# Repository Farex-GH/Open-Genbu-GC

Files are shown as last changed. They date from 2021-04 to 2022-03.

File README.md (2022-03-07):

# Open-Genbu-GC
Replacement PCB and firmware for Genbu Groove Coaster controllers

For firmware building and flashing instructions, see firmware/README.md.

Pre-built firmware is available in the Releases tab.

For PCB and schematic viewing, download KiCad and open the respective PCB/*.kicad_pro file.

## WIP

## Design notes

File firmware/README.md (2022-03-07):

BUILD INSTRUCTIONS

1. git clone the repsoitory

2. cd genbu-fw/firmware

3. git submodule update --init

4. ./setup,sh

5. mkdir build

6. cd build

7. cmake ..

8. make -j4

FIRMWARE FLASH INSTRUCTIONS

1. Plug in Raspberry Pi Pico to a PC. If reflashing, hold down the BOOTSEL button while plugging it in.

2. Copy genbu-fw.uf2 from build directory to Raspberry Pi Pico directory

DEBUGGING

1. See https://datasheets.raspberrypi.com/pico/getting-started-with-pico.pdf Ch.5 and 6.

There are useful macros provided for printing via UART and GPIO toggling.
For more timing sensitve situations, use the GPIO toggling to see when certain parts of code are hit.
Otherwise if timing is not a problem, DB_PRINT works fine.

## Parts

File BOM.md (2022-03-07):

# WIP
## Will be converted to an excel sheet for easier reading

2x SMR-03v-B from https://lcsc.com/product-detail/Rectangular-Connectors-Housings_JST-Sales-America-SMR-03V-B_C157907.html, plus wires
Or buy premade female connectors from Amazon if you search "ws2812b connector"

11x B4B-XH-A(LF)(SN) from https://lcsc.com/product-detail/Wire-To-Board-Wire-To-Wire-Connector_JST-Sales-America_B4B-XH-A-LF-SN_JST-Sales-America-B4B-XH-A-LF-SN_C144395.html

1x Pi Pico module from https://www.adafruit.com/product/4883 or wherever you can get it

1x USB-A to micro USB-B cable, for front PCB to Pi Pico.

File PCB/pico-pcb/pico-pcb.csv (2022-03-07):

Id | Designator | Package | Quantity | Designation | Supplier and ref
1 | J12,J13,J16 | PinSocket_1x03_P2.54mm_Vertical | 3 | Conn_01x03
2 | J15 | PinSocket_1x02_P2.54mm_Vertical | 1 | Conn_01x02
3 | J14 | PinSocket_1x04_P2.54mm_Vertical | 1 | Conn_01x04
4 | J1,J2,J3,J4,J5,J6,J7,J8,J9,J10,J11 | JST_B4B-XH-A(LF)(SN) | 11 | B4B-XH-A_LF__SN_
5 | U1 | RPi_Pico_SMD_TH | 1 | Pico

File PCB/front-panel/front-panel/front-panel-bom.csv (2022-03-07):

Id | Designator | Package | Quantity | Designation | Supplier and ref
1 | J2 | USB_A_Molex_105057_Vertical | 1 | USB_A
2 | J1 | USB_B_TE_5787834_Vertical | 1 | USB_B

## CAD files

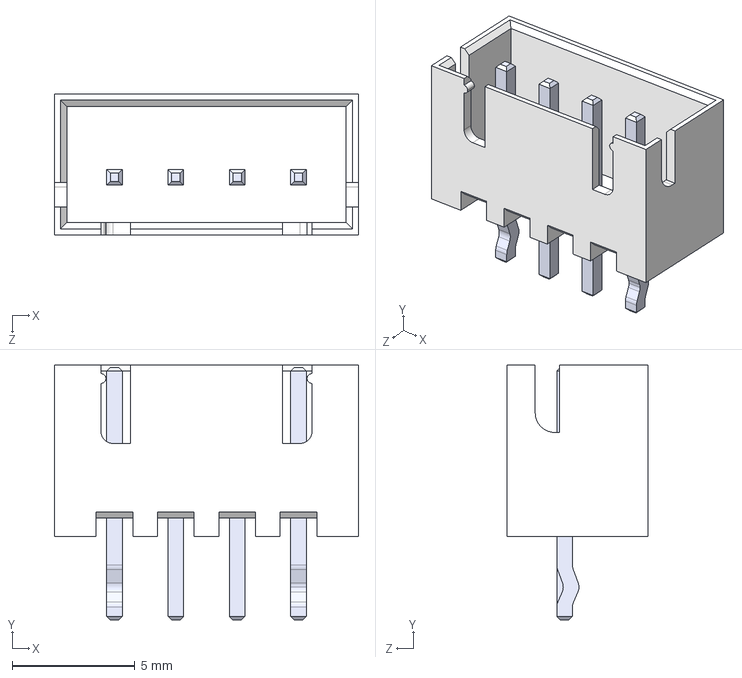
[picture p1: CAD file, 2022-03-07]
PCB/pico-pcb/RP_Silicon_KiCad/B4B-XH-A(LF)(SN)/B4B-XH-A_LF__SN_.step
12.4 x 10.4 x 5.75 mm

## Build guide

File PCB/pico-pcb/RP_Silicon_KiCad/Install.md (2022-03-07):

# Install KiCad libraries

## Manage Symbol Libraries

Accessed from the Preferences menu, add a new line with the +, give it a name and use the folder icon to point to the directory/folder where you have KiCadLibraries.

Manage Symbol Libraries screen shot


## Manage Footprint Libraries

Ditto! Accessed from the Preferences menu, add a new line with the +, give it a name and use the folder icon to point to the directory/folder where you have KiCadLibraries.

Manage Footprint Libraries screen shot


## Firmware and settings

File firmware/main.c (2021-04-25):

#include <stdlib.h>

#include "pico/stdlib.h"
#include "pico/multicore.h"

#include "proc_queue.h"
#include "usb_driver.h"
#include "usb_gamepad.h"
#include "utils.h"
#include "arm_utils.h"
#include "board_io.h"
#include "ws2812.h"

void control_loop(void)
{
    proc_info *proc;

    while (1) {
        proc = proc_next();
        if (proc) {
            proc->proc_fn(proc->pfn_args);
        } else {
            __DSB;
            __WFI;
        }
    }
}

void dbg_gpio_init(void)
{
    gpio_init(PIN_DBG_0);
    gpio_init(PIN_DBG_1);
    gpio_init(PIN_DBG_2);
    gpio_set_dir(PIN_DBG_0, true);
    gpio_set_dir(PIN_DBG_1, true);
    gpio_set_dir(PIN_DBG_2, true);
}

int main(void) {
    stdio_init_all();
    usb_ep_add_callback(0x81, ep1_in_cb);
    usb_ep_add_callback(0x02, ep2_out_cb);
    usb_device_init();
    proc_init();
    board_io_init();
    dbg_gpio_init();

    /*
     * In theory we could handle the WS2812s by using our priority queue, but
     * we have an entire core sitting idle, so put it to work.
     */
    multicore_launch_core1(handle_ring_led);

    /* Spin until USB is ready */
    /*
     * TODO: Something good to do would be to have some LED activity happening
     * while the device is enumerating.
     * Once enumerated, some other brief LED activity could happen.
     */
    while(!usb_is_configured());

    control_loop();

    return 0;
}

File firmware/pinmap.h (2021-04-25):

#ifndef PINMAP_H
#define PINMAP_H

#define BOOSTER_R_U 22
#define BOOSTER_R_R 21
#define BOOSTER_R_D 20
#define BOOSTER_R_L 19
#define BOOSTER_R_PRESS 18
#define BOOSTER_R_LED 17

#define BOOSTER_L_U 6
#define BOOSTER_L_R 7
#define BOOSTER_L_D 8
#define BOOSTER_L_L 9
#define BOOSTER_L_PRESS 10
#define BOOSTER_L_LED 11

#define BTN_START 5
#define BTN_START_LED 4

#define BOOSTER_L_WS2812_DIN 15
#define BOOSTER_L_NUM_WS2812 10
#define BOOSTER_R_WS2812_DIN 16
#define BOOSTER_R_NUM_WS2812 10

#define NUM_BTN 7
#define NUM_DPAD 4
#define NUM_WS2812 16

/*
 * Useful if we need to see where we are in code, but are in a time critical
 * situation where using a UART is too slow.
 */
#define PIN_DBG_0 12
#define PIN_DBG_1 13
#define PIN_DBG_2 14

#endif

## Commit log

2021-04-16 debug: Add GPIO debug code
    Eventually pin toggling within code will be removed later
2021-04-25 pinmap: Update GPIOs for PCB
2021-04-25 ws2812: Raise debug print threshold
    Lower threshold made it annoying to debug other problems, because CPU1
    would print in the middle of CPU0 printing.
2021-04-25 usb gamepad: Change button mapping ordering
    THe ordering is wrong because when developing, I had the buttons
    oriented the wrong way.
2021-04-25 debounce: board_io: Add debounce code
    v1 of debounce code, may be revised later.
    Button presses are very very very bouncy, so an ISR-driven pure firmware
    solution might not work.
    [board_io.c]
2021-04-25 board io: Misc comment fixes
    [board_io.c]
2021-04-25 main: Add LED feedback TODO
2021-04-25 usb driver: dead code and whitespace fixes
    No functional change
2021-04-25 usb driver: Add blurb saying how to use it
2021-05-04 descriptors: Use Genbu VID + PID
2022-03-07 firmware/TODO: Remove LED TODO
    LEDs were moved to the same core as USB execution.
2022-03-07 PCB/pico-pcb: Add rev 1.2.0
    [B4B-XH-A_LF__SN_.step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]
2022-03-07 firmware/board_io: Remove dead code
